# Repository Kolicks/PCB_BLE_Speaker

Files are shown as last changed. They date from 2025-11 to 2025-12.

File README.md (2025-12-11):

# 🔊 PCB_BLE_Speaker  
**BLE Audio + USB-C Rechargeable Speaker Board**

---

## 📘 Overview
**PCB_BLE_Speaker** is a compact **BLE audio speaker board** designed in **KiCad 9**, focused on learning about **USB-C**, **battery-powered systems**, **rechargeable devices**, and **audio amplifier integration**.  
The project explores practical design decisions such as **battery connectors**, **charging circuits**, **power protection**, and **audio MCU layout constraints**.

It includes two **MAX98357A** audio MCUs to experiment with both **mono** and **stereo firmware**, and was created as an exercise in **DFM/DFA**, power routing, and EMC-aware PCB design.

<p align="center">
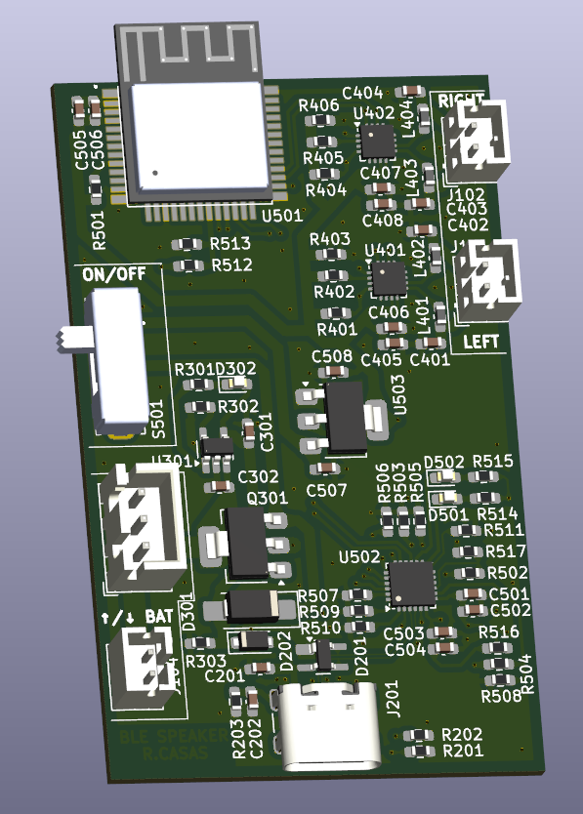
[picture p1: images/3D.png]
3D Render
  
  <br>
  <em>3D render of the PCB_BLE_Speaker board</em>
</p>

---

## ⚠️ FLAWS
- Serial Comms does not work, need extra circuitry for EN/BOOT between ESP32 and CP2102N.
- Be aware of the Audio connectors polarity. In this design you may need to solder on the opposite direction.

---

## ⚙️ General Information
- Designed in **KiCad 9** as a learning platform for:
  - USB-C 2.0 (5 V / 1 A)
  - Battery-powered systems
  - Rechargeable device architecture  
- Includes **two battery connectors**:  
  - One for a battery already owned  
  - One for a **standard battery connector** planned for purchase  
- Created to better understand **power protection**, **charging ICs**, and **audio layout constraints**.
- Built on a **4-layer PCB**, as recommended for the **MAX98357A** for better reliability, noise control, and ground integrity.
- All components intentionally placed on the **top layer** as a DFA/DFM exercise.

<p align="center">
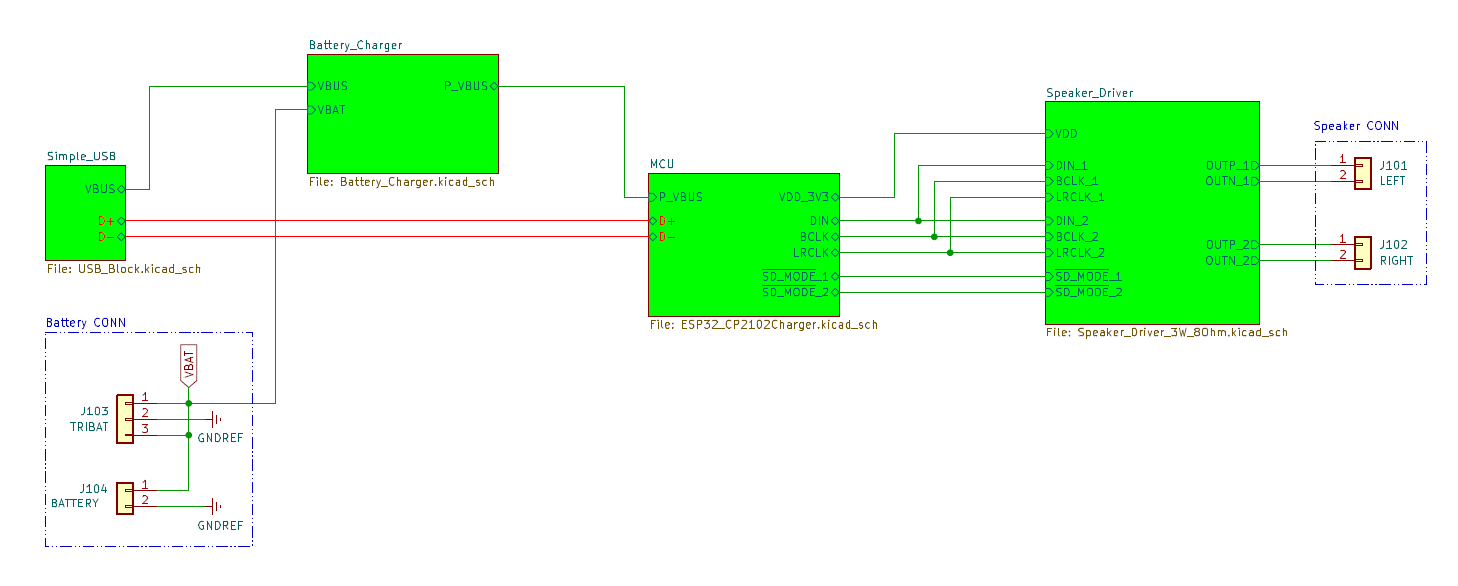
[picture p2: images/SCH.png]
Schematic
  
  <br>
  <em>Schematic (KiCad 9)</em>
</p>

---

## 🔊 Characteristics
- **USB-C 2.0** input supplying **5 V up to 1 A**.  
- **MCP73831-2-OT** Li-Ion charger with a **5 kΩ PROG resistor**, giving a safe **200 mA charge current** — chosen to reduce thermal risks since no temperature monitoring system is implemented.  
- **MOSFET protection circuitry** between USB-C and charger to manage correct power flow and avoid dangerous battery–USB backfeed conditions.  
- **Two MAX98357A audio MCUs** included:
  - Allows experimenting with **mono** and **stereo** BLE audio firmware.
- Intended for **battery operation**:
  - A DC/DC regulator would have improved efficiency, but was intentionally discarded for version 1 for simplicity.
- Observed layout improvement for next revision:
  - Placing **audio amplifier + charger + power supply** side by side to reduce **current loop area**, improving **EMC/EMI** behavior and reducing high-current noise.

<p align="center">
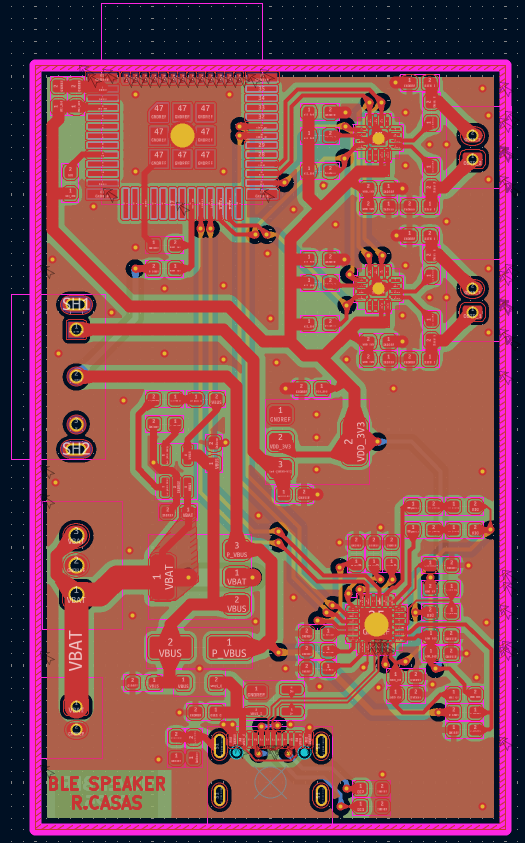
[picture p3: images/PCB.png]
PCB Layout
  
  <br>
  <em>PCB layout design</em>
</p>

---

## ⚠️ Known Issues / Notes
- Power architecture can be improved by using a **buck DC/DC converter** for better efficiency during battery operation.  
- Current loops of the audio + charger power path could be optimized by placing related components closer.  
- Future improvements should include:
  - Better **EMI loop minimization**  
  - Dedicated copper pours for high-current paths  
  - Additional filtering  
- Placement of both audio MCUs on the top layer made routing more challenging, but was kept intentionally as a DFM/DFA practice exercise.
- Rechargable Battery circuitry WORKS as expected!
---

## 🧩 Files and Structure

<p align="center">
  <a href="https://github.com/YourRepo/PCB_BLE_Speaker" target="_blank">
    
  </a>
</p>

PCB_BLE_Speaker/
├── schematic/
├── pcb_layout/
├── gerbers/
├── images/
├── LICENSE
└── README.md

---

## 📜 License
This hardware design is released under the **CERN Open Hardware License v2 – Permissive (CERN-OHL-P-2.0)**.  
You may use, modify, and redistribute the design, as long as:
- You include the license in redistributions.
- You give proper credit to the original author.

---

## 👤 Author
**Project:** PCB_BLE_Speaker  
**Author:** Kolicks  
**Toolchain:** KiCad 9  
**Version:** 1.0  

---

## 🧱 Future Improvements
- **Power Efficiency**
  - Add a **buck DC/DC converter** to improve battery runtime and reduce heat.  
- **EMI-Aware Layout**
  - Place **charger + power supply + audio MCUs** adjacently to shrink high-current loops.  
- **User Indicators**
  - Add **charging, power, and battery status LEDs**.  
- **Battery Protection**
  - Add optional **NTC thermistor** for thermal monitoring.  
- **Usability**
  - Improve connector positioning and silkscreen clarity.
  - Add circuitry for Serial to make it reliable.
  - Change MCU to another one more suitable for Hand Soldering.

---

⭐ *If this project interests you, feel free to star the repository or contribute with suggestions!*

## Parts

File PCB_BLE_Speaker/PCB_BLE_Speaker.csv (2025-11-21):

Reference | Qty | Value | DNP | Exclude from BOM | Exclude from Board | Footprint | Datasheet
C201,C202,C401,C402,C403,C404,C406,C408,C504,C506 | 10 | 100nF/50V |  |  |  | Capacitor_SMD:C_0603_1608Metric_Pad1.08x0.95mm_HandSolder | ~
C301,C503 | 2 | 4.7uF/50V |  |  |  | Capacitor_SMD:C_0603_1608Metric_Pad1.08x0.95mm_HandSolder | ~
C302,C405,C407,C505 | 4 | 10uF/50V |  |  |  | Capacitor_SMD:C_0603_1608Metric_Pad1.08x0.95mm_HandSolder | ~
C501,C502,C507 | 3 | 1uF/50V |  |  |  | Capacitor_SMD:C_0603_1608Metric_Pad1.08x0.95mm_HandSolder | ~
C508 | 1 | 2.2uF/50V |  |  |  | Capacitor_SMD:C_0603_1608Metric_Pad1.08x0.95mm_HandSolder | ~
D201 | 1 | SP0503BAHT |  |  |  | Package_TO_SOT_SMD:SOT-143_Handsoldering | http://www.littelfuse.com/~/media/files/littelfuse/technical%20resources/documents/data%20sheets/sp05xxba.pdf
D202 | 1 | 1N5819HW-7-F |  |  |  | Diode_SMD:D_SOD-123F
D301 | 1 | SS34 |  |  |  | Diode_SMD:D_SMA_Handsoldering | https://www.vishay.com/docs/88751/ss32.pdf
D302,D501,D502 | 3 | LED |  |  |  | LED_SMD:LED_0603_1608Metric_Pad1.05x0.95mm_HandSolder | ~
J101 | 1 | LEFT |  |  |  | Connector_JST:JST_PH_B2B-PH-K_1x02_P2.00mm_Vertical | ~
J102 | 1 | RIGHT |  |  |  | Connector_JST:JST_PH_B2B-PH-K_1x02_P2.00mm_Vertical | ~
J103 | 1 | TRIBAT |  |  |  | Connector_JST:JST_XH_B3B-XH-A_1x03_P2.50mm_Vertical | ~
J104 | 1 | BATTERY |  |  |  | Connector_JST:JST_PH_B2B-PH-K_1x02_P2.00mm_Vertical | ~
J201 | 1 | USB_C_Receptacle_USB2.0_16P |  |  |  | Connector_USB:USB_C_Receptacle_GCT_USB4105-xx-A_16P_TopMnt_Horizontal
L401,L402,L403,L404 | 4 | L |  |  |  | Inductor_SMD:L_0603_1608Metric_Pad1.05x0.95mm_HandSolder | ~
Q301 | 1 | PMOS |  |  |  | Generic_RCO:SOT-223_ISP20EP10LMXTSA1
R201,R202 | 2 | 5k1 |  |  |  | Resistor_SMD:R_0603_1608Metric_Pad0.98x0.95mm_HandSolder | ~
R203 | 1 | 100M |  |  |  | Resistor_SMD:R_0603_1608Metric_Pad0.98x0.95mm_HandSolder | ~
R301 | 1 | 4.7k |  |  |  | Resistor_SMD:R_0603_1608Metric_Pad0.98x0.95mm_HandSolder | ~
R302 | 1 | 5k |  |  |  | Resistor_SMD:R_0603_1608Metric_Pad0.98x0.95mm_HandSolder | ~
R303,R501,R503,R505,R506,R507,R509,R510,R511 | 9 | 10k |  |  |  | Resistor_SMD:R_0603_1608Metric_Pad0.98x0.95mm_HandSolder | ~
R401,R402,R403,R404,R405,R406 | 6 | R |  |  |  | Resistor_SMD:R_0603_1608Metric_Pad0.98x0.95mm_HandSolder | ~
R502,R514,R515 | 3 | 1k |  |  |  | Resistor_SMD:R_0603_1608Metric_Pad0.98x0.95mm_HandSolder | ~
R504 | 1 | 22.1k |  |  |  | Resistor_SMD:R_0603_1608Metric_Pad0.98x0.95mm_HandSolder | ~
R508 | 1 | 47.5k |  |  |  | Resistor_SMD:R_0603_1608Metric_Pad0.98x0.95mm_HandSolder | ~
R512 | 1 | 75k |  |  |  | Resistor_SMD:R_0603_1608Metric_Pad0.98x0.95mm_HandSolder | ~
R513 | 1 | 100k |  |  |  | Resistor_SMD:R_0603_1608Metric_Pad0.98x0.95mm_HandSolder | ~
R516,R517 | 2 | 0 |  |  |  | Resistor_SMD:R_0603_1608Metric_Pad0.98x0.95mm_HandSolder | ~
S501 | 1 | SLW-1277545-3A-RA-N-D |  |  |  | Switch_RCO:SW_SLW-1277545-3A-RA-N-D
U301 | 1 | MCP73831-2-OT |  |  |  | Package_TO_SOT_SMD:SOT-23-5_HandSoldering | http://ww1.microchip.com/downloads/en/DeviceDoc/20001984g.pdf
U401,U402 | 2 | MAX98357A |  |  |  | Generic_RCO:TQFN-16-1EP_3x3mm_P0.5mm_EP1.23x1.23mm | https://www.analog.com/media/en/technical-documentation/data-sheets/MAX98357A-MAX98357B.pdf
U501 | 1 | ESP32-H2-MINI-1-H2 |  |  |  | ESP_32_Modules:MODULE_ESP32-H2-MINI-1-H2_NO_Thermal
U502 | 1 | CP2102N-Axx-xQFN24 |  |  |  | Generic_RCO:QFN-24-1EP_4x4mm_P0.5mm_EP2.65x2.65mm | https://www.silabs.com/documents/public/data-sheets/cp2102n-datasheet.pdf
U503 | 1 | TLV76133DCY |  |  |  | Package_TO_SOT_SMD:SOT-223-3_TabPin2 | https://www.ti.com/lit/ds/symlink/tlv761.pdf

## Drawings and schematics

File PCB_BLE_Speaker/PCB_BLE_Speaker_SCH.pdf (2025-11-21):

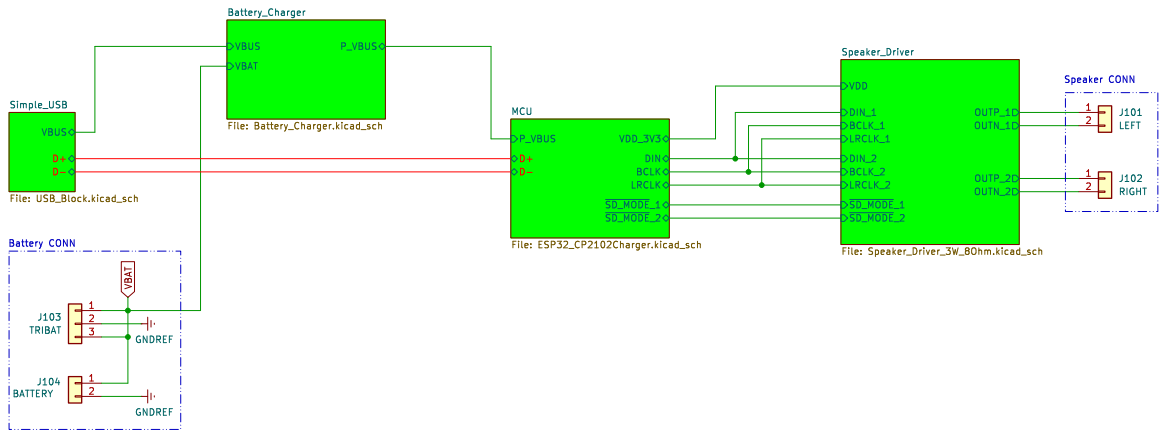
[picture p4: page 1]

Id: 1/5 Title: PCB_BLE_Speaker File: PCB_BLE_Speaker.kicad_sch Sheet: /

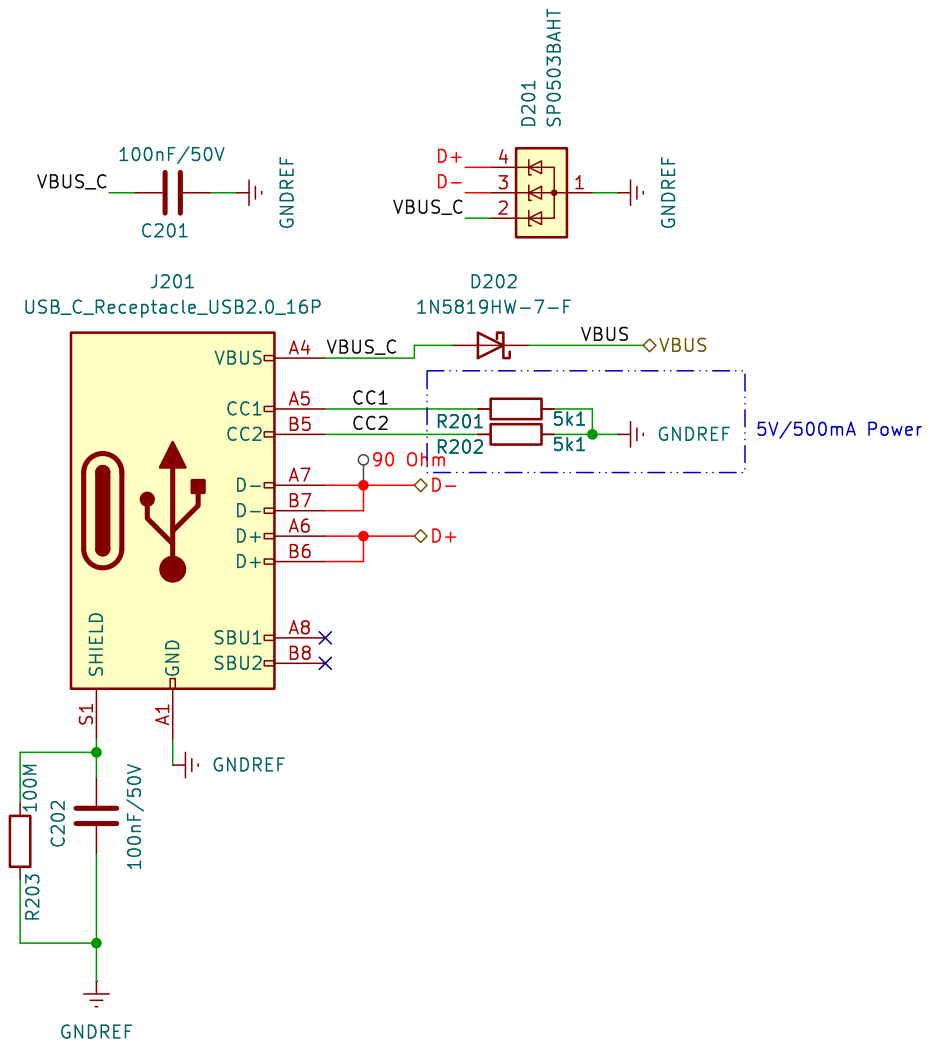
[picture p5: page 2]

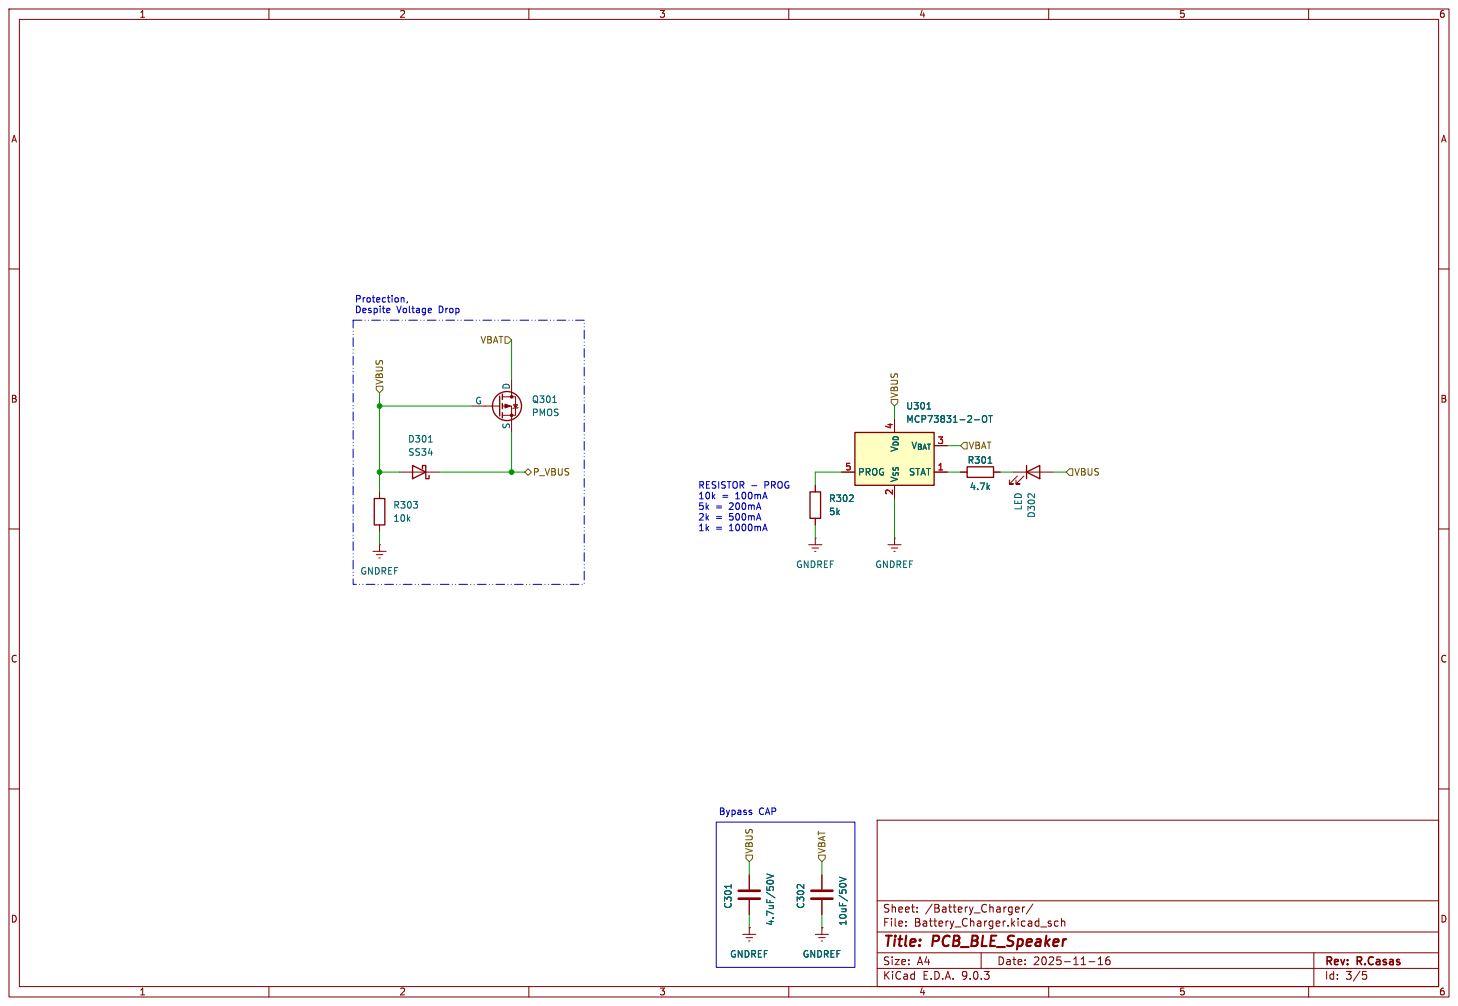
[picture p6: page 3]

Protection, Despite Voltage Drop

Id: 3/5 Title: PCB_BLE_Speaker File: Battery_Charger.kicad_sch Sheet: /Battery_Charger/ GNDREF GNDREF

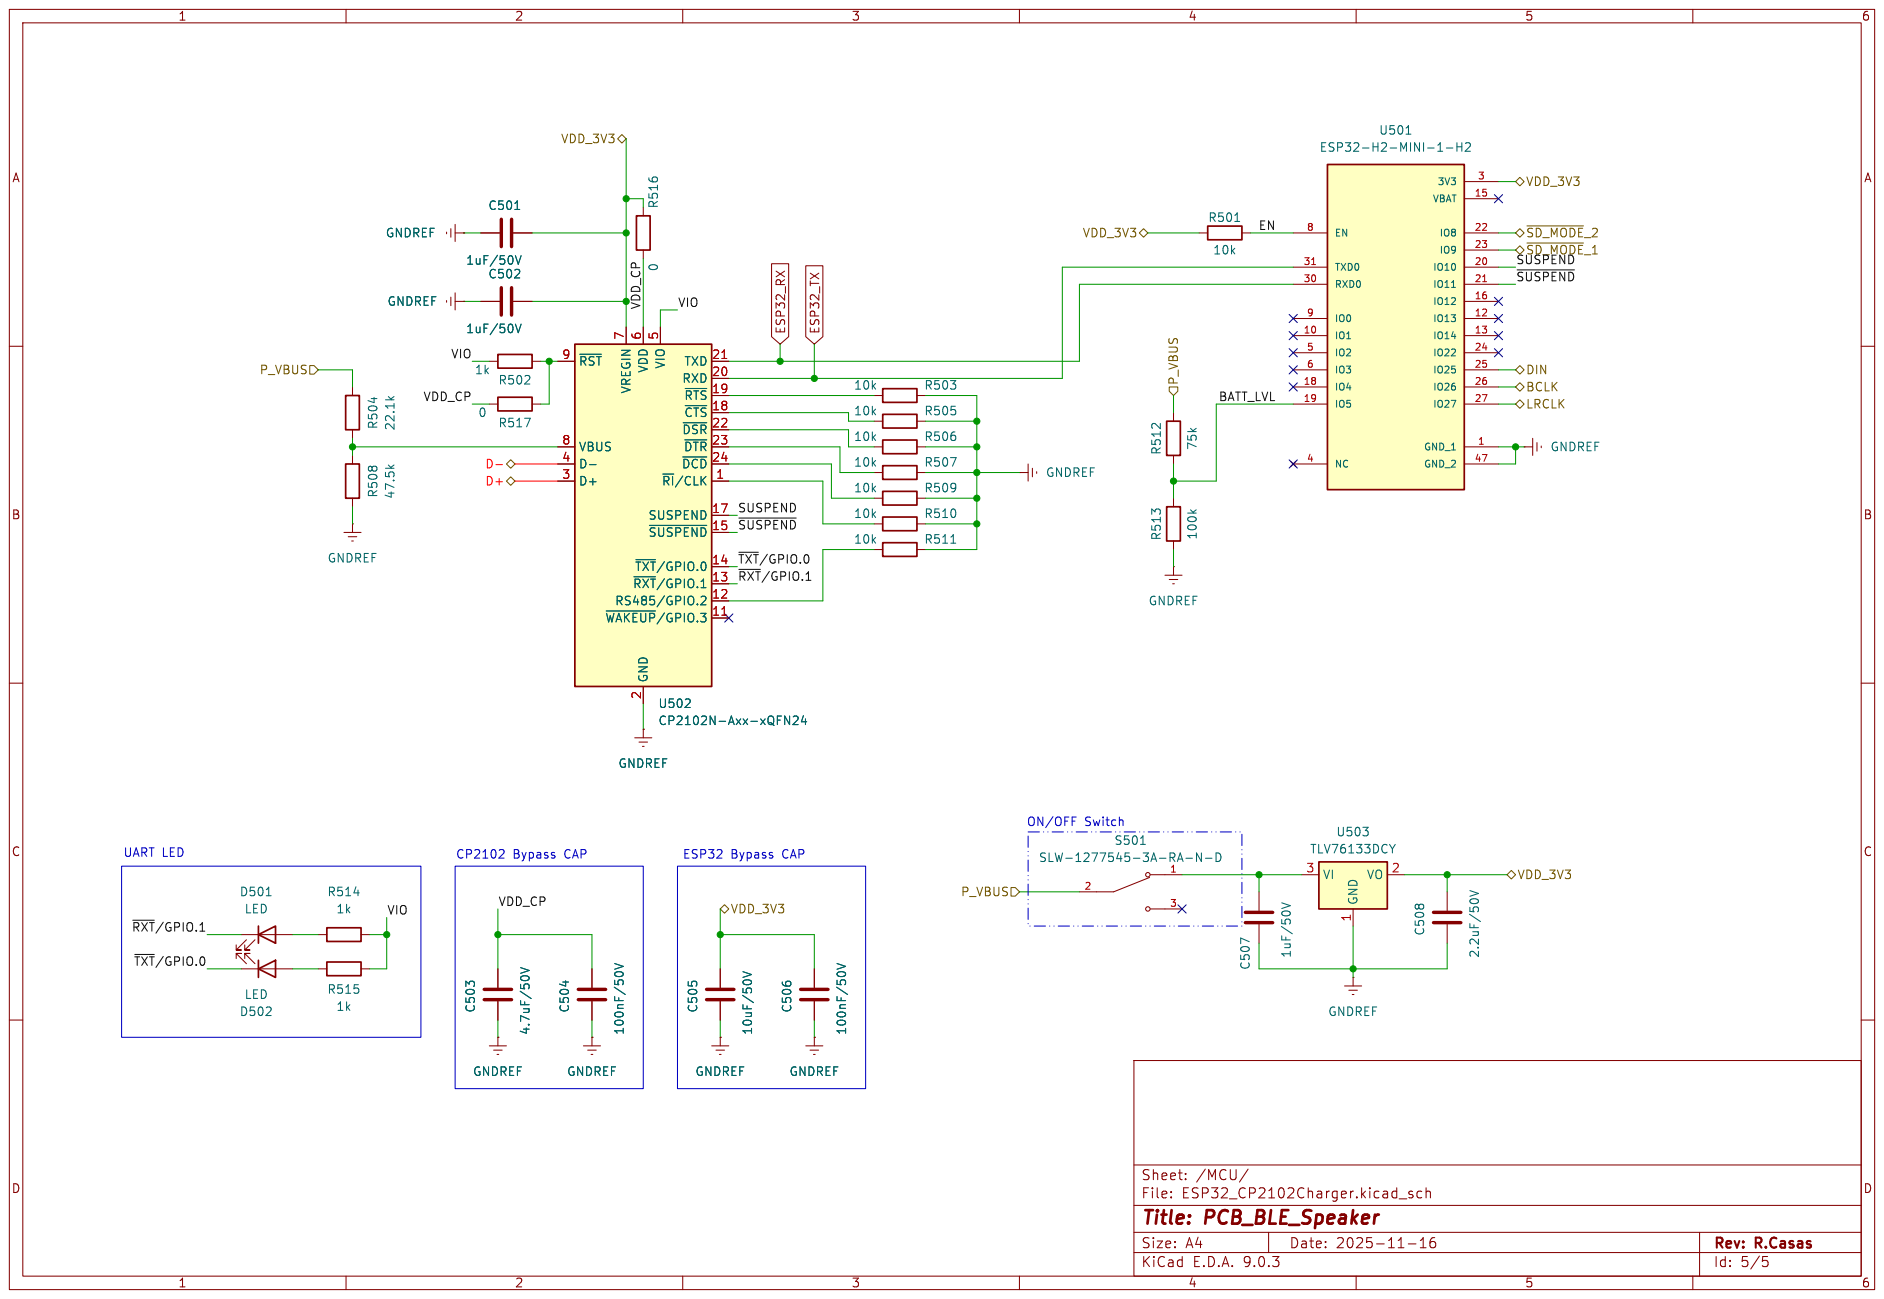
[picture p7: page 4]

5 TXD 21 RXD 20 ~{RTS} 19 ~{CTS} 18 ~{DSR} 22 ~{DTR} 23 ~{DCD} 24 ~{RI}/CLK1 SUSPEND 17 ~{SUSPEND}15 ~{TXT}/GPIO.014 ~{RXT}/GPIO.113 RS485/GPIO.2 12 ~{WAKEUP}/GPIO.311 GNDREF C502

5 TXD 21 RXD 20 ~{RTS} 19 ~{CTS} 18 ~{DSR} 22 ~{DTR} 23 ~{DCD} 24 ~{RI}/CLK1 SUSPEND 17 ~{SUSPEND}15 ~{TXT}/GPIO.014 ~{RXT}/GPIO.113 RS485/GPIO.2 12 ~{WAKEUP}/GPIO.311 U502 CP2102N-Axx-xQFN24

Id: 5/5 Title: PCB_BLE_Speaker File: ESP32_CP2102Charger.kicad_sch Sheet: /MCU/

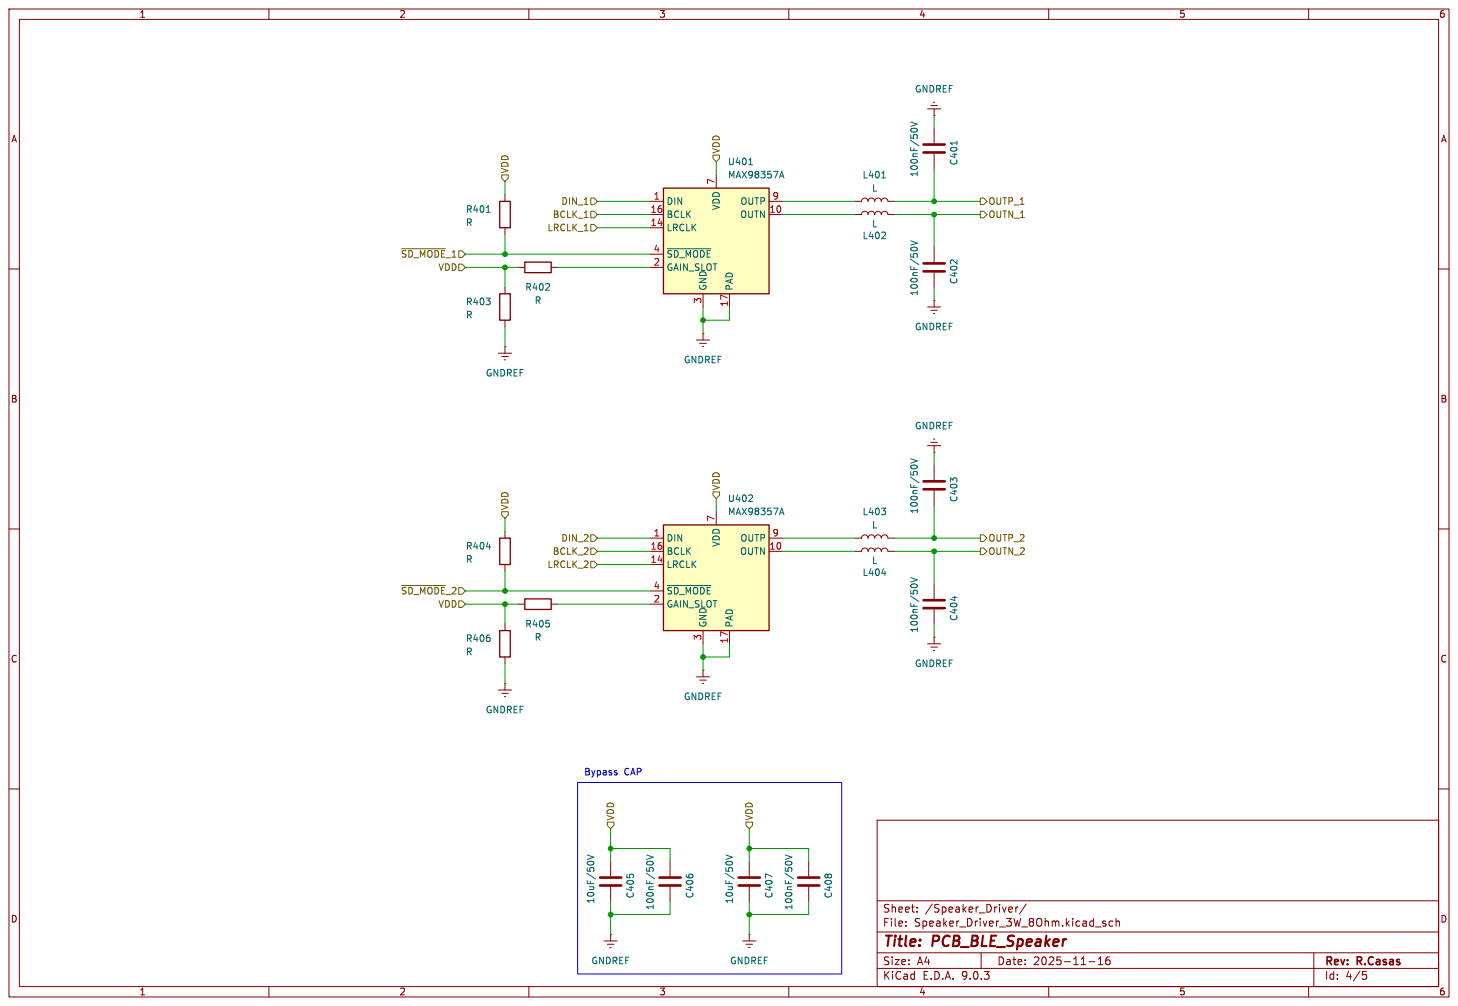
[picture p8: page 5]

Id: 4/5 Title: PCB_BLE_Speaker File: Speaker_Driver_3W_8Ohm.kicad_sch Sheet: /Speaker_Driver/

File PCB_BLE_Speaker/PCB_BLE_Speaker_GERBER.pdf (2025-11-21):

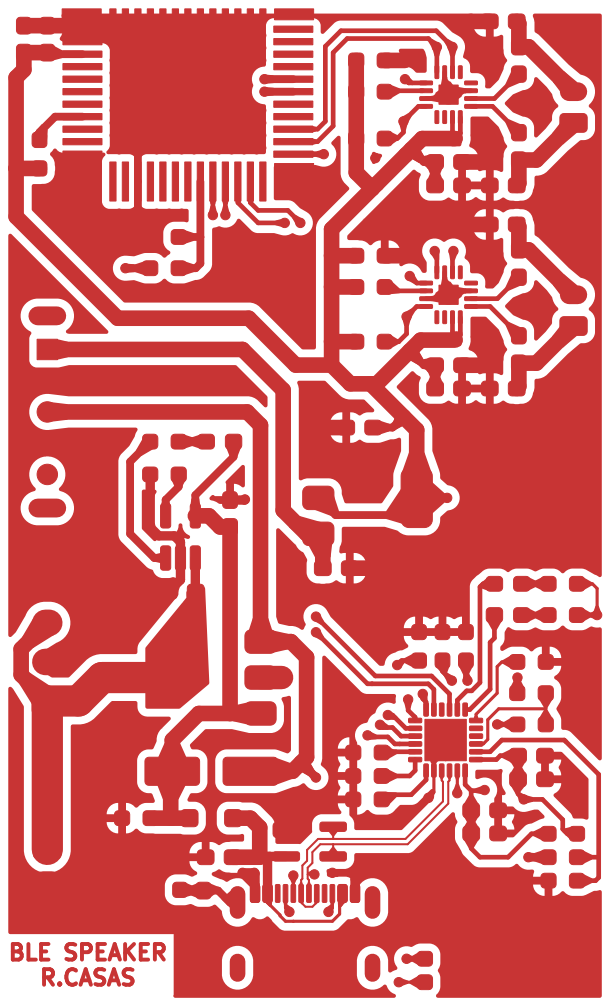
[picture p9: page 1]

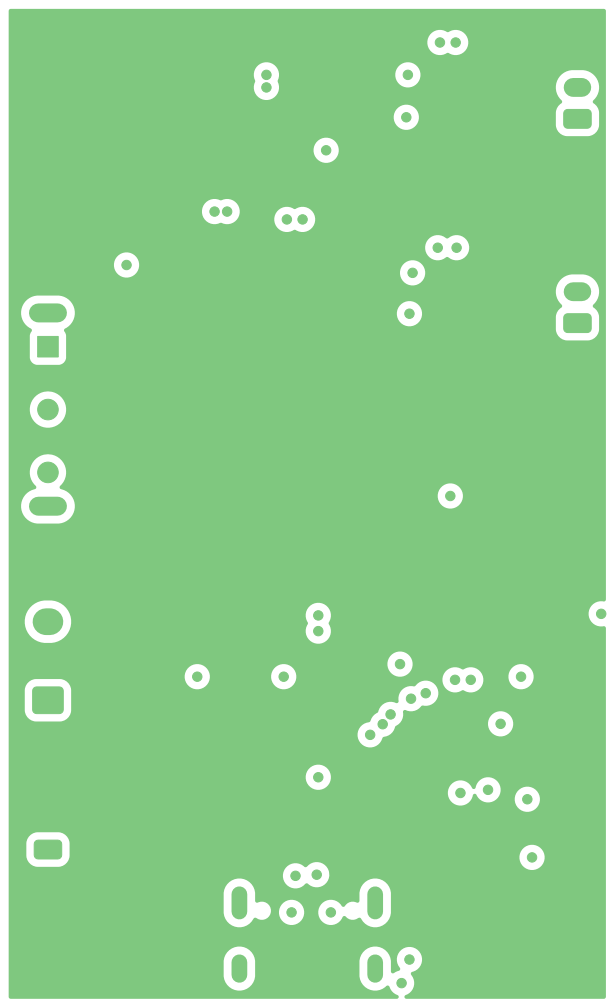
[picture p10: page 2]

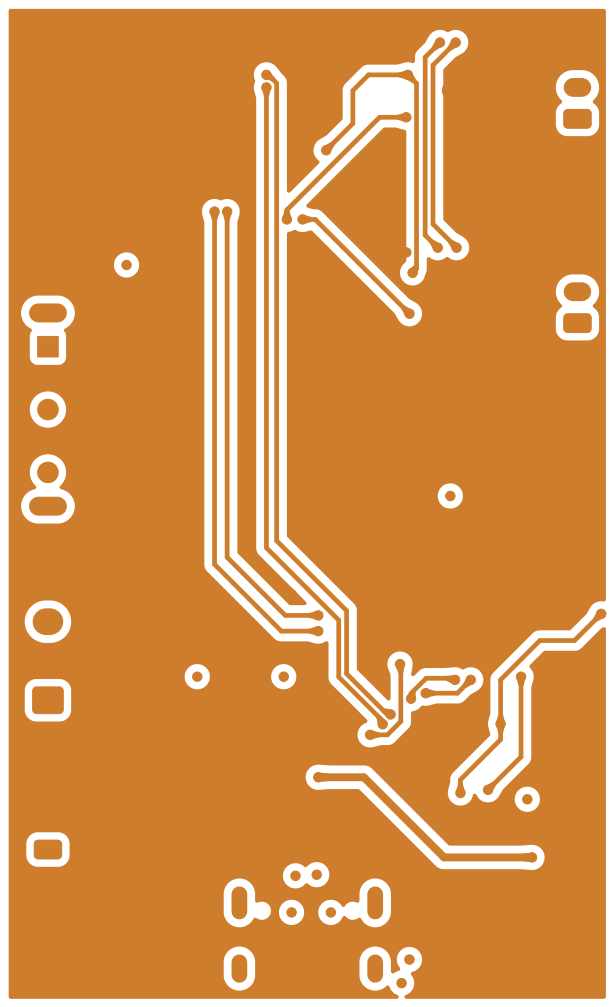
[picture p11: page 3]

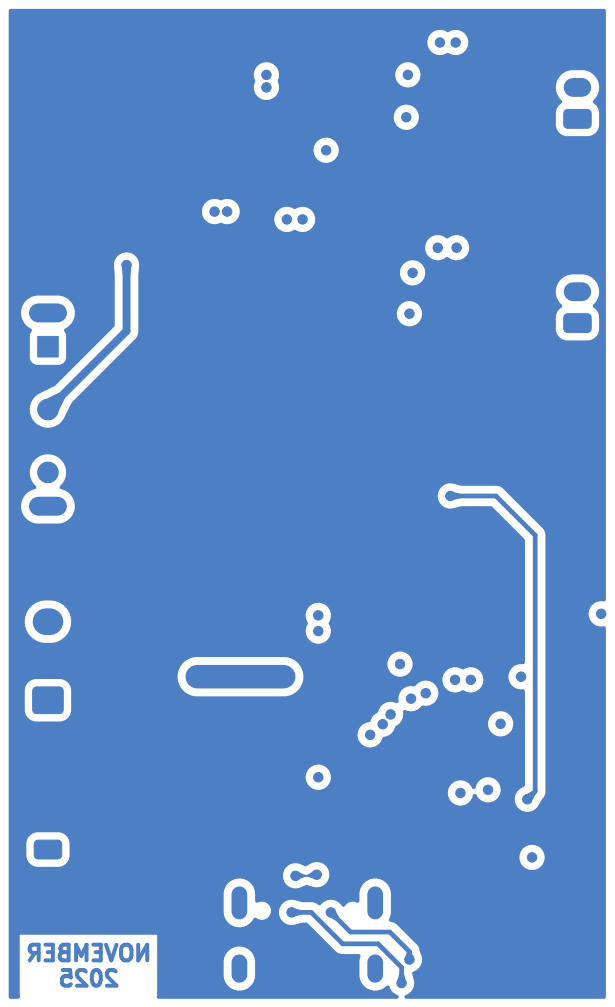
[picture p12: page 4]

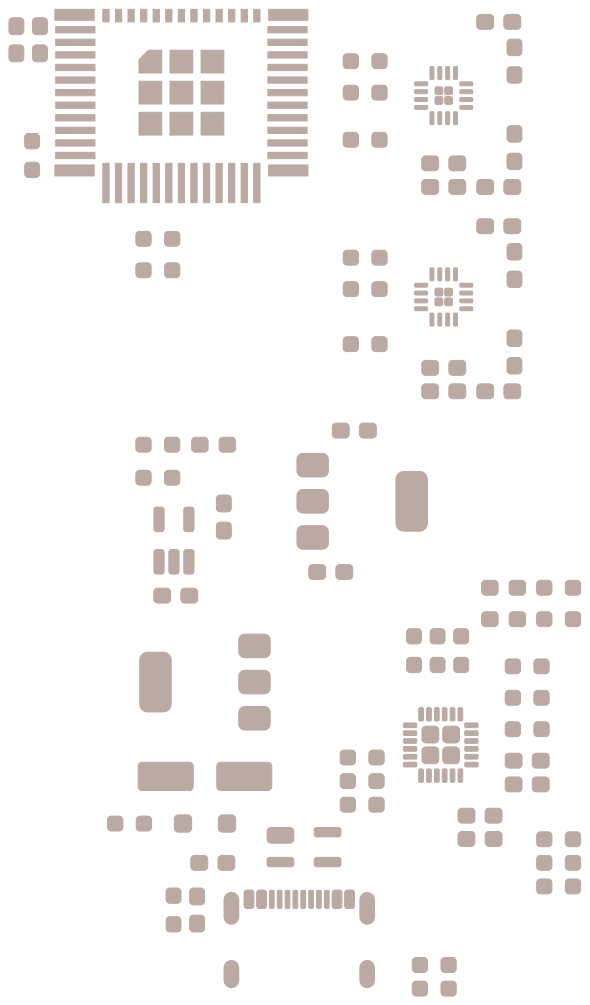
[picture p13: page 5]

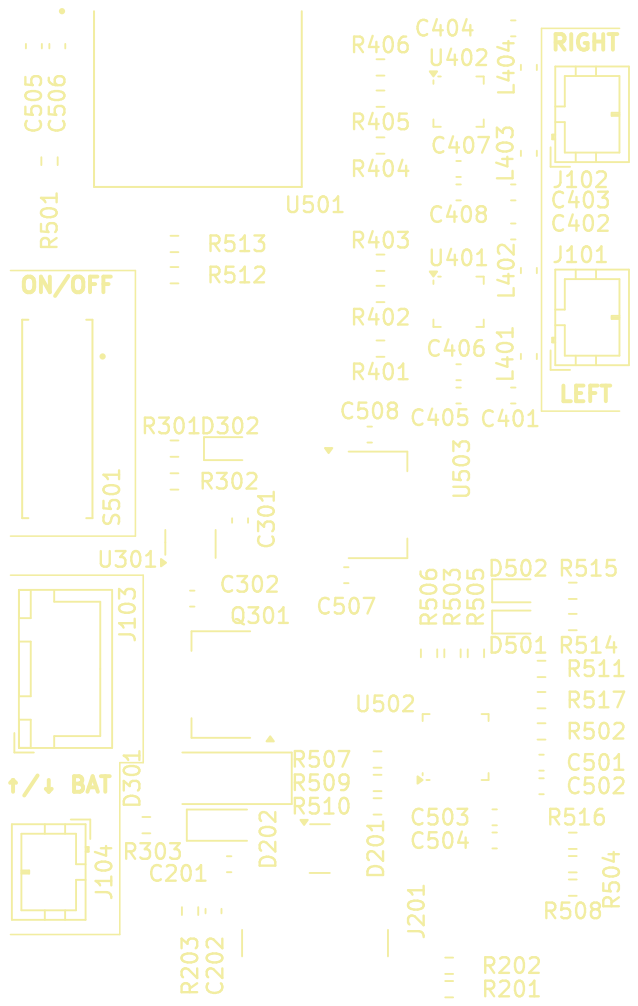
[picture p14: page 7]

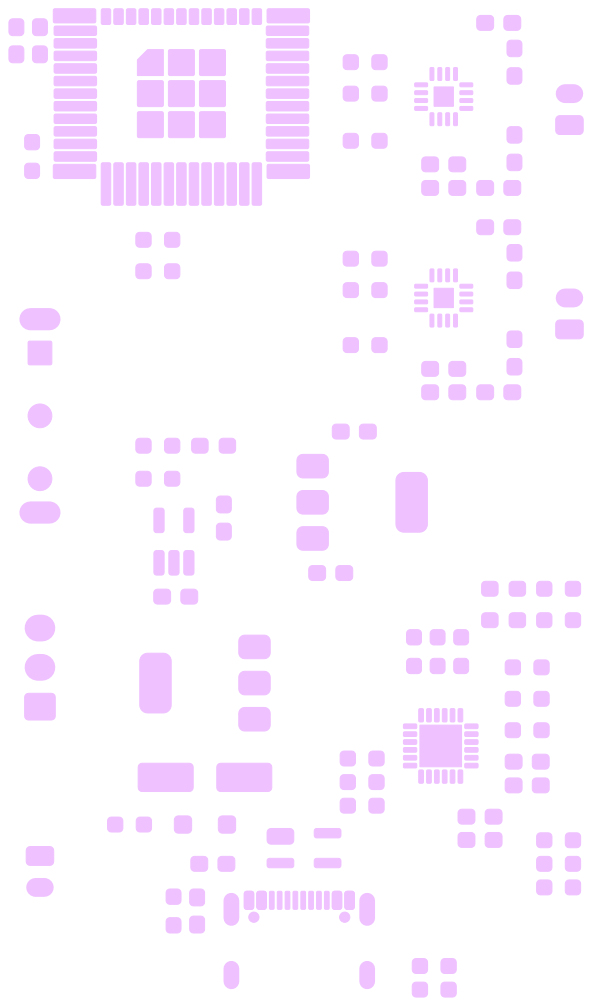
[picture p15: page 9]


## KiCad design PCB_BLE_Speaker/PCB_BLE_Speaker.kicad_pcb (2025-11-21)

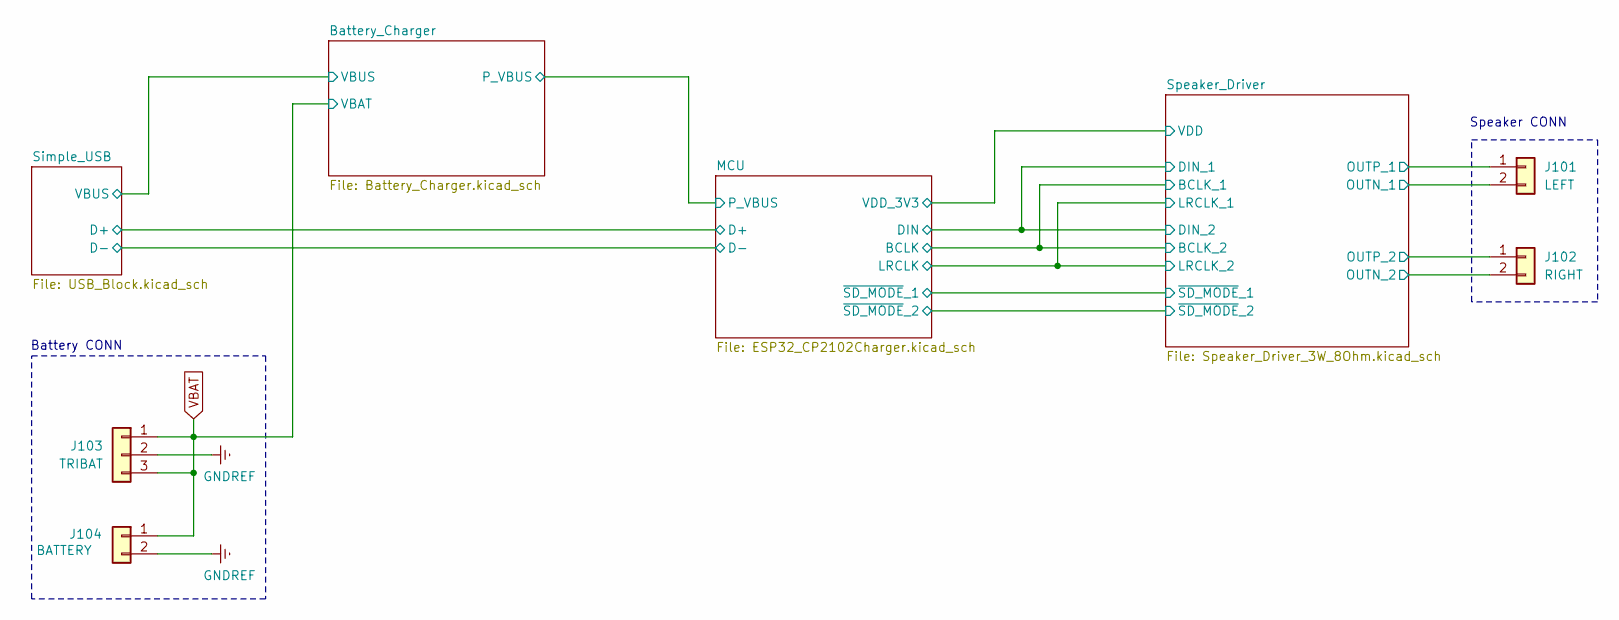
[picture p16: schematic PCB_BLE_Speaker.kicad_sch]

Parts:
J101: LEFT; JST_PH_B2B-PH-K_1x02_P2.00mm_Vertical
J102: RIGHT; JST_PH_B2B-PH-K_1x02_P2.00mm_Vertical
J103: TRIBAT; JST_XH_B3B-XH-A_1x03_P2.50mm_Vertical
J104: BATTERY; JST_PH_B2B-PH-K_1x02_P2.00mm_Vertical

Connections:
/Speaker_Driver/OUTN_1: J101.2; also elsewhere on the board
/Speaker_Driver/OUTN_2: J102.2; also elsewhere on the board
/Speaker_Driver/OUTP_1: J101.1; also elsewhere on the board
/Speaker_Driver/OUTP_2: J102.1; also elsewhere on the board
GNDREF: J103.2, J104.2; also elsewhere on the board
VBAT: J103.1, J103.3, J104.1; also elsewhere on the board

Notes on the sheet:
Battery CONN
Speaker CONN

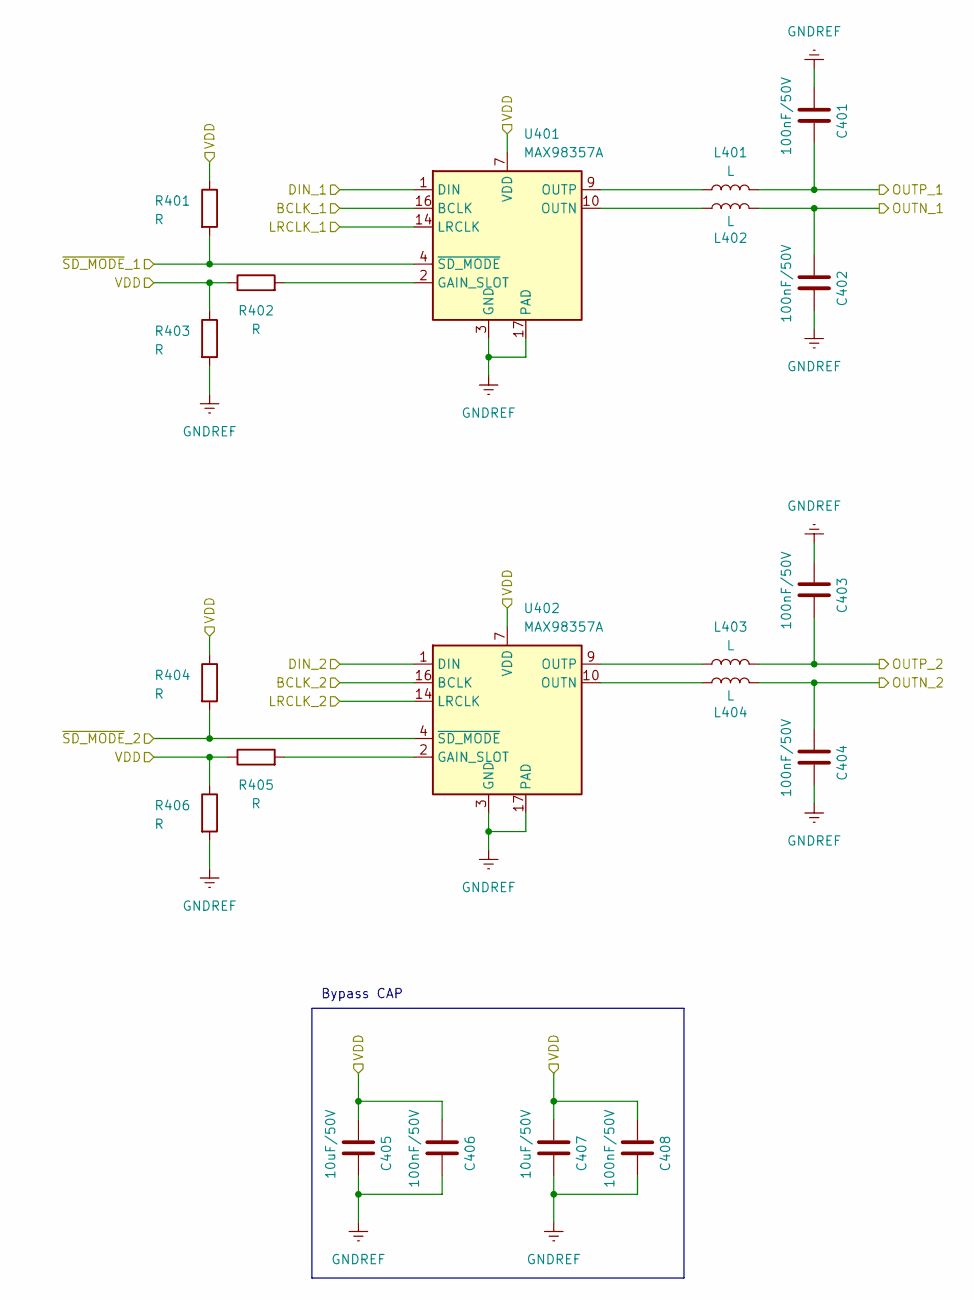
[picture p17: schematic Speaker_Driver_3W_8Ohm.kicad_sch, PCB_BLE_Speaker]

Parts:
C401, C402, C403, C404, C406, C408: 100nF/50V; C_0603_1608Metric_Pad1.08x0.95mm_HandSolder
C405, C407: 10uF/50V; C_0603_1608Metric_Pad1.08x0.95mm_HandSolder
L401, L402, L403, L404: L; L_0603_1608Metric_Pad1.05x0.95mm_HandSolder
R401, R402, R403, R404, R405, R406: R; R_0603_1608Metric_Pad0.98x0.95mm_HandSolder
U401, U402: MAX98357A; TQFN-16-1EP_3x3mm_P0.5mm_EP1.23x1.23mm

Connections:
/MCU/BCLK: U401.16 (BCLK), U402.16 (BCLK); also elsewhere on the board
/MCU/DIN: U401.1 (DIN), U402.1 (DIN); also elsewhere on the board
/MCU/LRCLK: U401.14 (LRCLK), U402.14 (LRCLK); also elsewhere on the board
/MCU/VDD_3V3: C405.2, C406.2, C407.2, C408.2, R401.1, R402.1, R403.1, R404.1, R405.1, R406.1, U401.7 (VDD), U401.8 (VDD), U402.7 (VDD), U402.8 (VDD); also elsewhere on the board
/MCU/~SD_MODE_1: R401.2, U401.4 (~SD_MODE); also elsewhere on the board
/MCU/~SD_MODE_2: R404.2, U402.4 (~SD_MODE); also elsewhere on the board
/Speaker_Driver/OUTN_1: C402.2, L402.2; also elsewhere on the board
/Speaker_Driver/OUTN_2: C404.2, L404.2; also elsewhere on the board
/Speaker_Driver/OUTP_1: C401.1, L401.2; also elsewhere on the board
/Speaker_Driver/OUTP_2: C403.1, L403.2; also elsewhere on the board
GNDREF: C401.2, C402.1, C403.2, C404.1, C405.1, C406.1, C407.1, C408.1, R403.2, R406.2, U401.3 (GND), U401.11 (GND), U401.15 (GND), U401.17 (PAD), U402.3 (GND), U402.11 (GND), U402.15 (GND), U402.17 (PAD); also elsewhere on the board
unnamed: R402.2, U401.2 (GAIN_SLOT)
unnamed: L402.1, U401.10 (OUTN)
unnamed: L401.1, U401.9 (OUTP)
unnamed: R405.2, U402.2 (GAIN_SLOT)
unnamed: L404.1, U402.10 (OUTN)
unnamed: L403.1, U402.9 (OUTP)

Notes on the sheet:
Bypass CAP

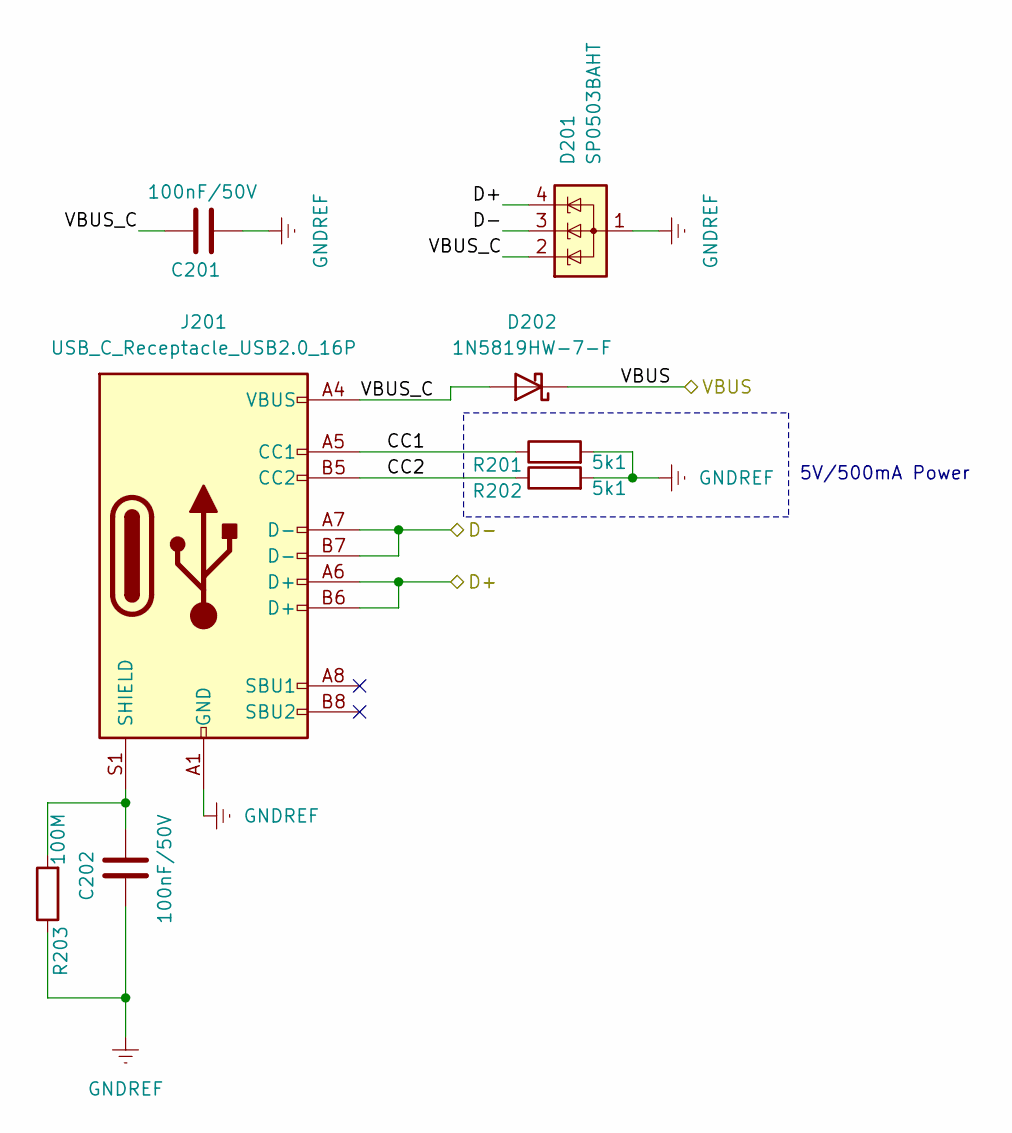
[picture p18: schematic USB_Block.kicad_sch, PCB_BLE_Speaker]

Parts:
C201, C202: 100nF/50V; C_0603_1608Metric_Pad1.08x0.95mm_HandSolder
D201: SP0503BAHT; SOT-143_Handsoldering
D202: 1N5819HW-7-F; D_SOD-123F
J201: USB_C_Receptacle_USB2.0_16P; USB_C_Receptacle_GCT_USB4105-xx-A_16P_TopMnt_Horizontal
R201, R202: 5k1; R_0603_1608Metric_Pad0.98x0.95mm_HandSolder
R203: 100M; R_0603_1608Metric_Pad0.98x0.95mm_HandSolder

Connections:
/Simple_USB/CC1: J201.A5 (CC1), R201.1
/Simple_USB/CC2: J201.B5 (CC2), R202.1
/Simple_USB/D+: D201.4 (K), J201.A6 (D+), J201.B6 (D+); also elsewhere on the board
/Simple_USB/D-: D201.3 (K), J201.A7 (D-), J201.B7 (D-); also elsewhere on the board
/Simple_USB/VBUS: D202.1 (K); also elsewhere on the board
/Simple_USB/VBUS_C: C201.1, D201.2 (K), D202.2 (A), J201.A4 (VBUS), J201.A9 (VBUS), J201.B4 (VBUS), J201.B9 (VBUS)
GNDREF: C201.2, C202.1, D201.1 (A), J201.A1 (GND), J201.A12 (GND), J201.B1 (GND), J201.B12 (GND), R201.2, R202.2, R203.1; also elsewhere on the board
unnamed: C202.2, J201.S1 (SHIELD), R203.2

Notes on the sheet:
5V/500mA Power

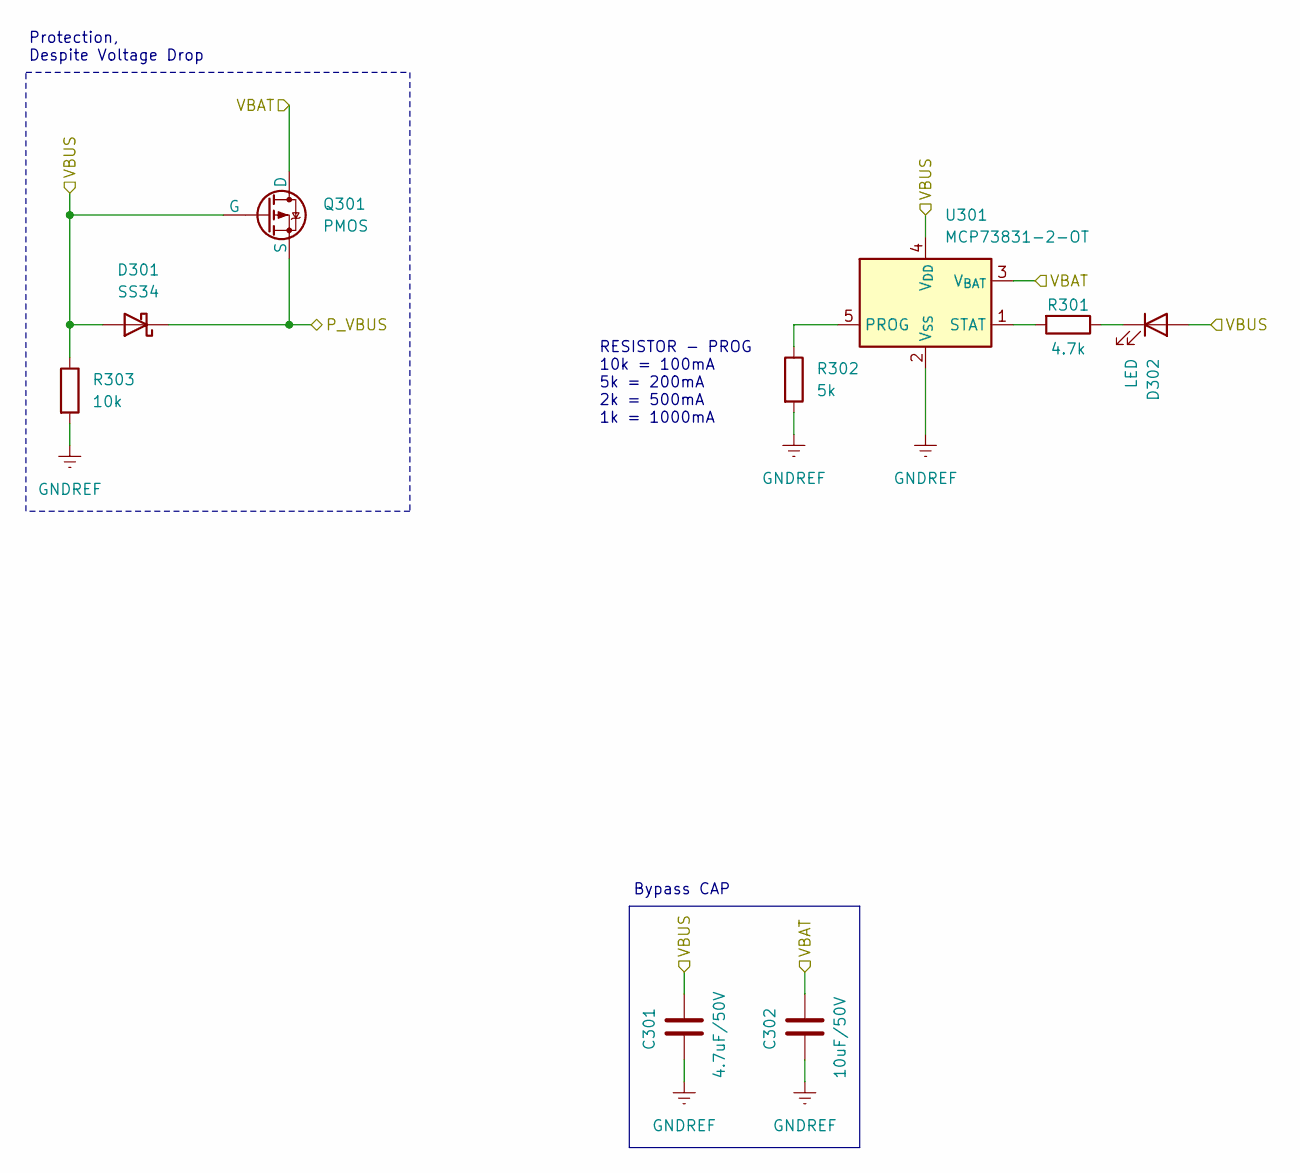
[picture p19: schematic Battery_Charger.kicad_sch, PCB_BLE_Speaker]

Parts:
C301: 4.7uF/50V; C_0603_1608Metric_Pad1.08x0.95mm_HandSolder
C302: 10uF/50V; C_0603_1608Metric_Pad1.08x0.95mm_HandSolder
D301: SS34; D_SMA_Handsoldering
D302: LED; LED_0603_1608Metric_Pad1.05x0.95mm_HandSolder
Q301: PMOS; SOT-223_ISP20EP10LMXTSA1
R301: 4.7k; R_0603_1608Metric_Pad0.98x0.95mm_HandSolder
R302: 5k; R_0603_1608Metric_Pad0.98x0.95mm_HandSolder
R303: 10k; R_0603_1608Metric_Pad0.98x0.95mm_HandSolder
U301: MCP73831-2-OT; SOT-23-5_HandSoldering

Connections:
/Battery_Charger/P_VBUS: D301.1 (K), Q301.3 (S); also elsewhere on the board
/Simple_USB/VBUS: C301.1, D301.2 (A), D302.2 (A), Q301.2 (G), R303.1, U301.4 (V_{DD}); also elsewhere on the board
GNDREF: C301.2, C302.2, R302.2, R303.2, U301.2 (V_{SS}); also elsewhere on the board
unnamed: D302.1 (K), R301.1
unnamed: R302.1, U301.5 (PROG)
unnamed: R301.2, U301.1 (STAT)
VBAT: C302.1, Q301.1 (D), U301.3 (V_{BAT}); also elsewhere on the board

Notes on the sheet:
Bypass CAP
Protection, Despite Voltage Drop
RESISTOR - PROG 10k = 100mA 5k = 200mA 2k = 500mA 1k = 1000mA

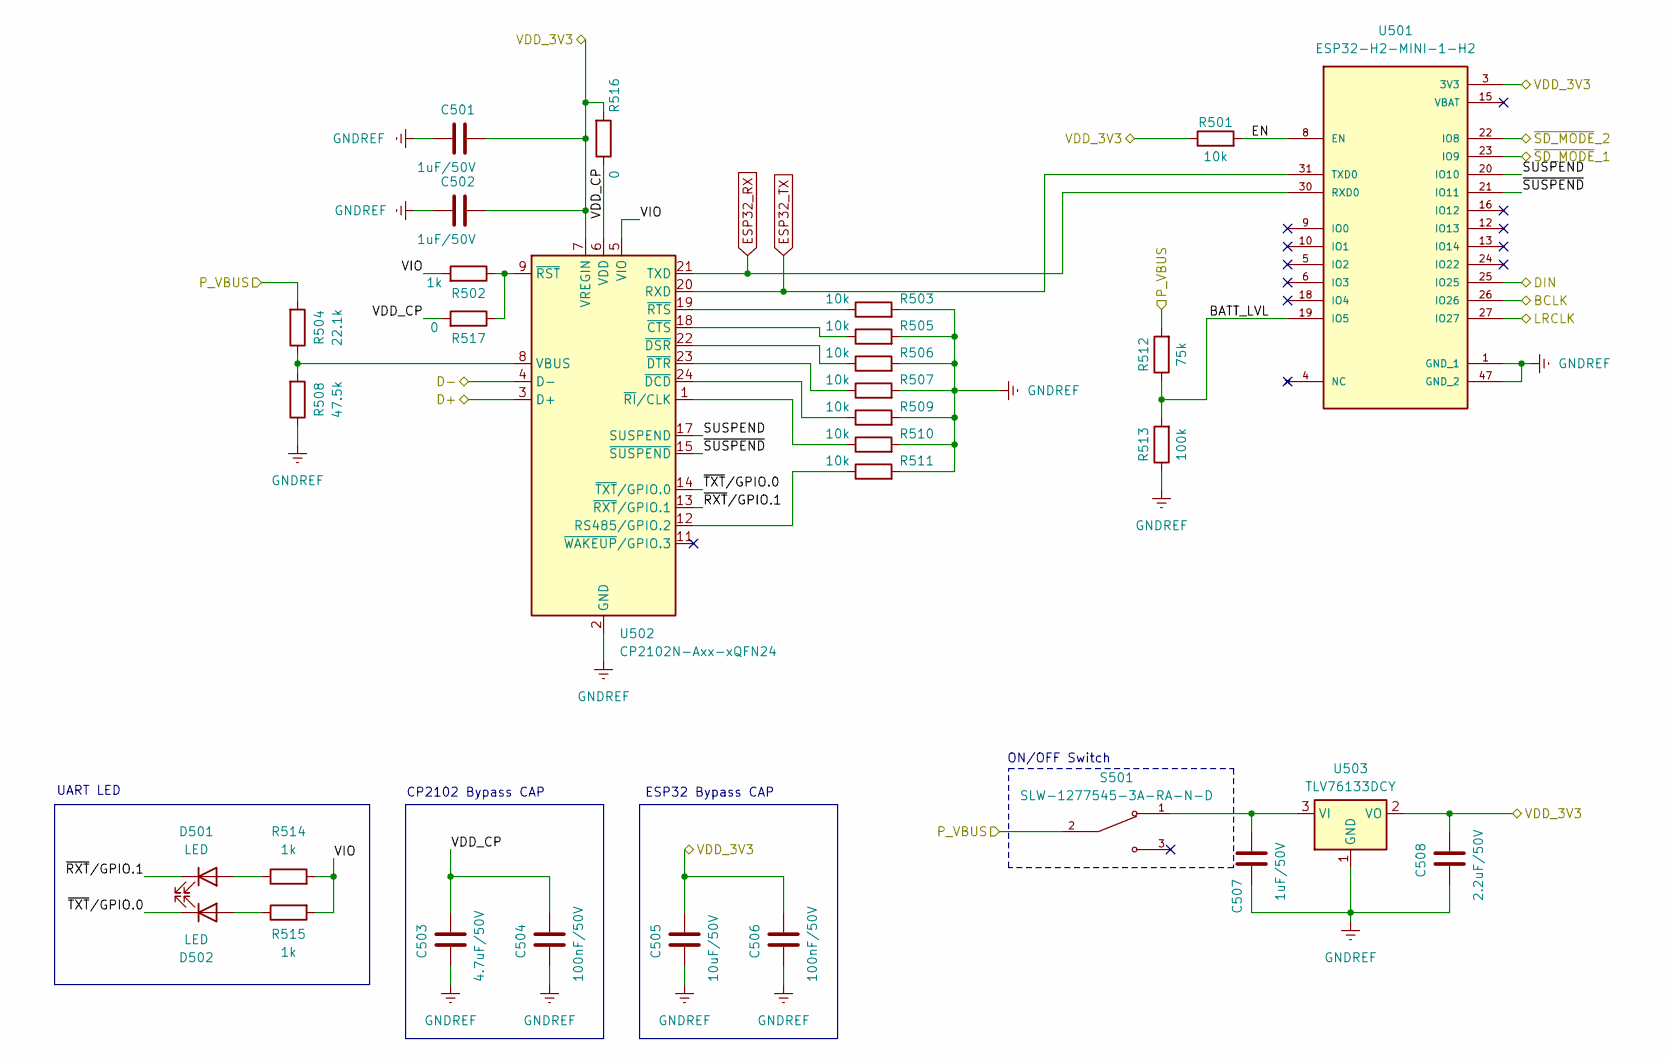
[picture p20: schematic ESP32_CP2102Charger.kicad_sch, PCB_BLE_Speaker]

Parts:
C501, C502, C507: 1uF/50V; C_0603_1608Metric_Pad1.08x0.95mm_HandSolder
C503: 4.7uF/50V; C_0603_1608Metric_Pad1.08x0.95mm_HandSolder
C504, C506: 100nF/50V; C_0603_1608Metric_Pad1.08x0.95mm_HandSolder
C505: 10uF/50V; C_0603_1608Metric_Pad1.08x0.95mm_HandSolder
C508: 2.2uF/50V; C_0603_1608Metric_Pad1.08x0.95mm_HandSolder
D501, D502: LED; LED_0603_1608Metric_Pad1.05x0.95mm_HandSolder
R501, R503, R505, R506, R507, R509, R510, R511: 10k; R_0603_1608Metric_Pad0.98x0.95mm_HandSolder
R502, R514, R515: 1k; R_0603_1608Metric_Pad0.98x0.95mm_HandSolder
R504: 22.1k; R_0603_1608Metric_Pad0.98x0.95mm_HandSolder
R508: 47.5k; R_0603_1608Metric_Pad0.98x0.95mm_HandSolder
R512: 75k; R_0603_1608Metric_Pad0.98x0.95mm_HandSolder
R513: 100k; R_0603_1608Metric_Pad0.98x0.95mm_HandSolder
R516, R517: 0; R_0603_1608Metric_Pad0.98x0.95mm_HandSolder
S501: SLW-1277545-3A-RA-N-D; SW_SLW-1277545-3A-RA-N-D; PARTREV 1.01
U501: ESP32-H2-MINI-1-H2; MODULE_ESP32-H2-MINI-1-H2_NO_Thermal; PARTREV v0.5
U502: CP2102N-Axx-xQFN24; QFN-24-1EP_4x4mm_P0.5mm_EP2.65x2.65mm
U503: TLV76133DCY; SOT-223-3_TabPin2

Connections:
/Battery_Charger/P_VBUS: R504.2, R512.2, S501.2; also elsewhere on the board
/MCU/BATT_LVL: R512.1, R513.2, U501.19 (IO5)
/MCU/BCLK: U501.26 (IO26); also elsewhere on the board
/MCU/DIN: U501.25 (IO25); also elsewhere on the board
/MCU/EN: R501.2, U501.8 (EN)
/MCU/LRCLK: U501.27 (IO27); also elsewhere on the board
/MCU/SUSPEND: U501.20 (IO10), U502.17 (SUSPEND)
/MCU/VDD_3V3: C501.1, C502.1, C505.1, C506.1, C508.1, R501.1, R516.2, U501.3 (3V3), U502.7 (VREGIN), U503.2 (VO); also elsewhere on the board
/MCU/VDD_CP: C503.1, C504.1, R516.1, R517.2, U502.6 (VDD)
/MCU/VIO: R502.2, R514.2, R515.2, U502.5 (VIO)
/MCU/~RXT/GPIO.1: D501.1 (K), U502.13 (~RXT/GPIO.1)
/MCU/~SD_MODE_1: U501.23 (IO9); also elsewhere on the board
/MCU/~SD_MODE_2: U501.22 (IO8); also elsewhere on the board
/MCU/~SUSPEND: U501.21 (IO11), U502.15 (~SUSPEND)
/MCU/~TXT/GPIO.0: D502.1 (K), U502.14 (~TXT/GPIO.0)
/Simple_USB/D+: U502.3 (D+); also elsewhere on the board
/Simple_USB/D-: U502.4 (D-); also elsewhere on the board
ESP32_RX: U501.30 (RXD0), U502.21 (TXD)
ESP32_TX: U501.31 (TXD0), U502.20 (RXD)
GNDREF: C501.2, C502.2, C503.2, C504.2, C505.2, C506.2, C507.2, C508.2, R503.2, R505.2, R506.2, R507.2, R508.1, R509.2, R510.2, R511.2, R513.1, U501.1 (GND_1), U501.47 (GND_2), U502.2 (GND), U502.25 (GND), U503.1 (GND); also elsewhere on the board
NC: U501.4 (NC), U501.7 (NC)
unnamed: D501.2 (A), R514.1
unnamed: D502.2 (A), R515.1
unnamed: R511.1, U502.12 (RS485/GPIO.2)
unnamed: R504.1, R508.2, U502.8 (VBUS)
unnamed: R505.1, U502.18 (~CTS)
unnamed: R509.1, U502.24 (~DCD)
unnamed: R506.1, U502.22 (~DSR)
unnamed: R507.1, U502.23 (~DTR)
unnamed: R510.1, U502.1 (~RI/CLK)
unnamed: R502.1, R517.1, U502.9 (~RST)
unnamed: R503.1, U502.19 (~RTS)
unnamed: C507.1, S501.1, U503.3 (VI)

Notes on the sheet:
CP2102 Bypass CAP
UART LED
ON/OFF Switch
ESP32 Bypass CAP

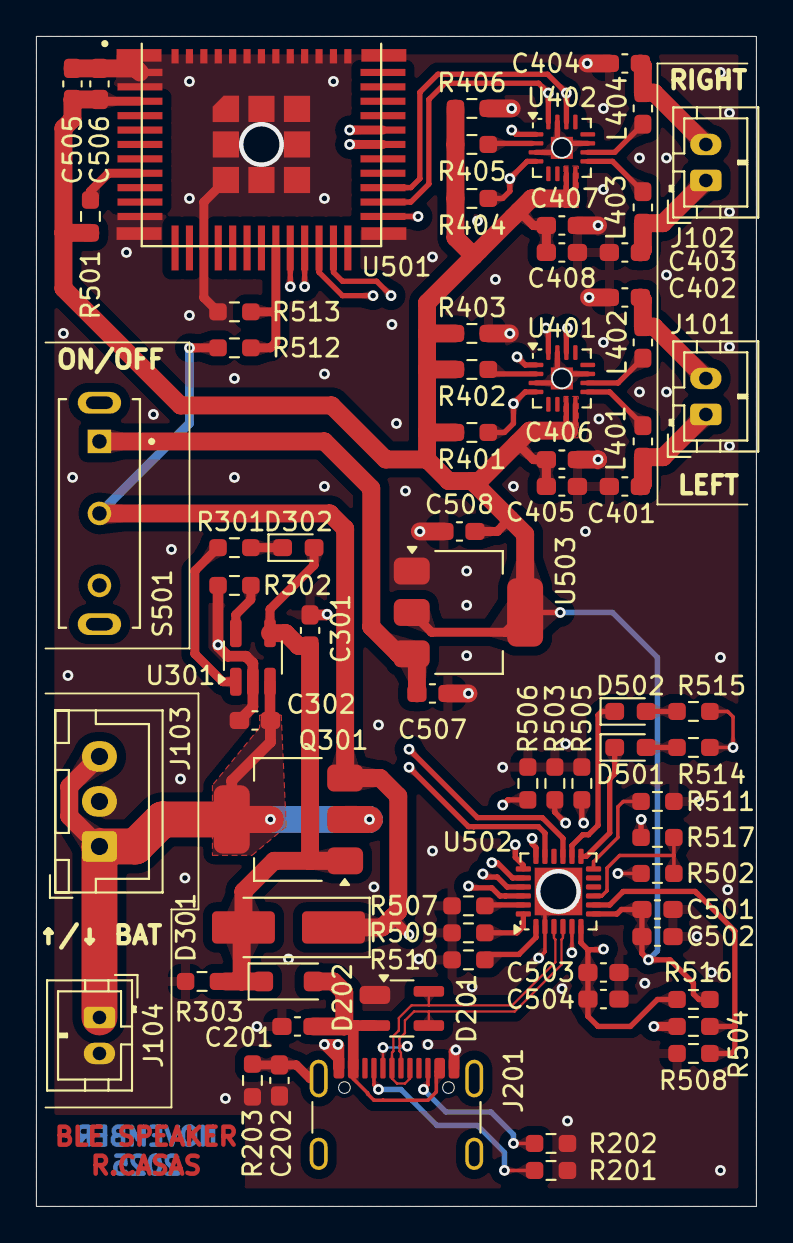
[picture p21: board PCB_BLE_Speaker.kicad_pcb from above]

Board: 4 copper layers, 40.0 x 65.0 mm, 72 parts (0 on the bottom side), 51 nets.

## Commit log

2025-12-11 Update README to remove PCB production note
    Removed production test note from README.
2025-12-11 Update README with rechargeable battery status
    Updated README to reflect working rechargeable battery circuitry.
2025-12-11 Enhance usability with Serial circuitry and MCU change
    Added circuitry for Serial reliability and changed MCU for better hand soldering.
